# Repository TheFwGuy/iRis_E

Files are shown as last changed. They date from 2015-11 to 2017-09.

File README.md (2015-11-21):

iRis project with Energia

To compile, Set Energia to have the library included and open iRis.ino.
This directory should be placed in the main directory where the sketches are
kept.

It is necessary to have these libraries installed in the library directory:

- LCD_protocol_terminal
- LCD_screen
- LiquidCrystal
- SD
- Adafruit_Sensor_master
- Adafruit_TSL2561_master

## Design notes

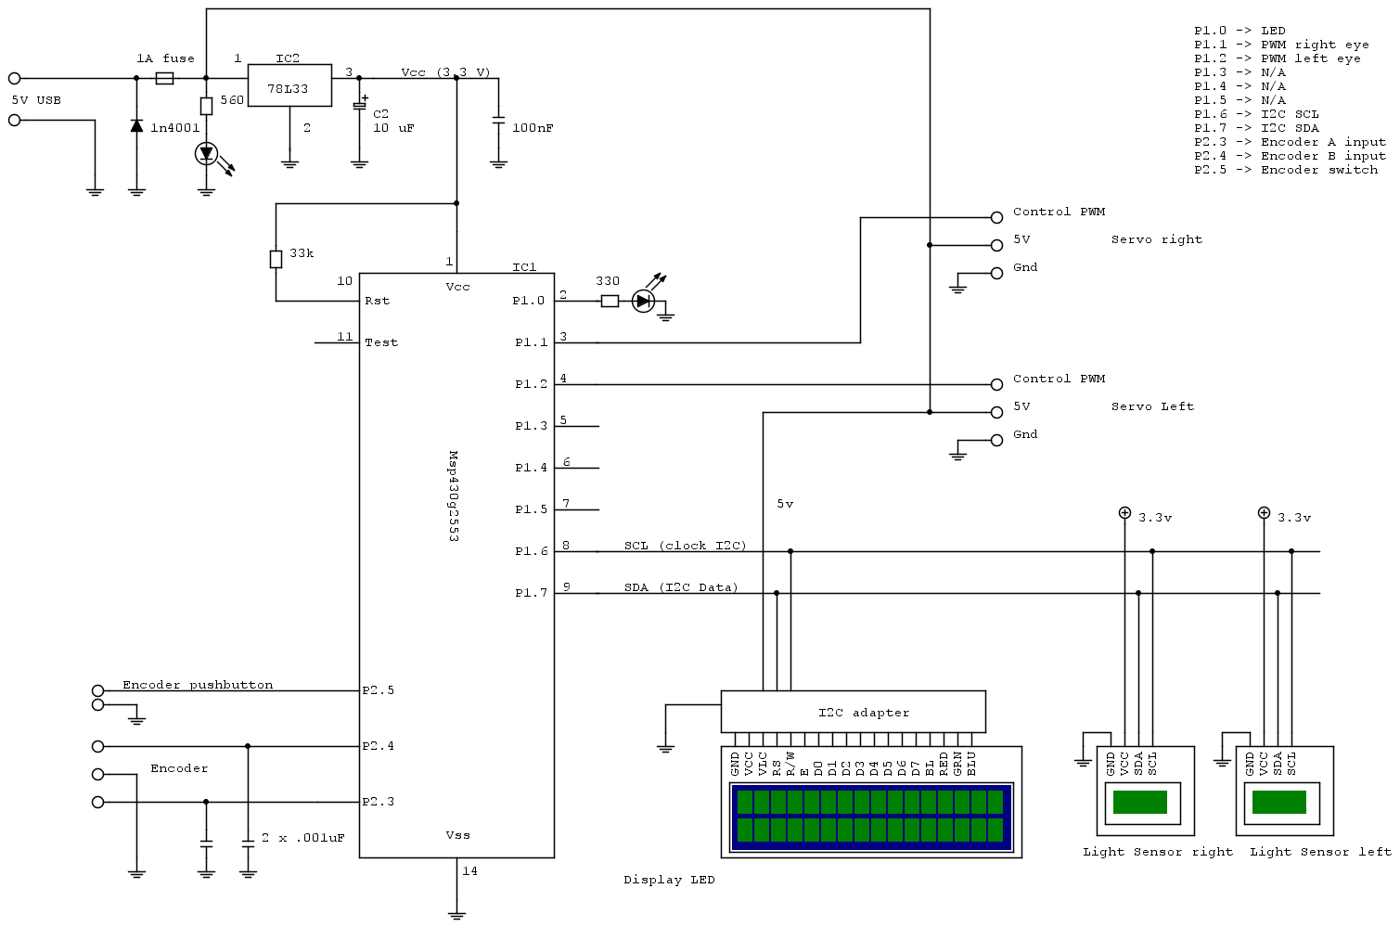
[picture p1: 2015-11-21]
Fidocad/iris_energia.png

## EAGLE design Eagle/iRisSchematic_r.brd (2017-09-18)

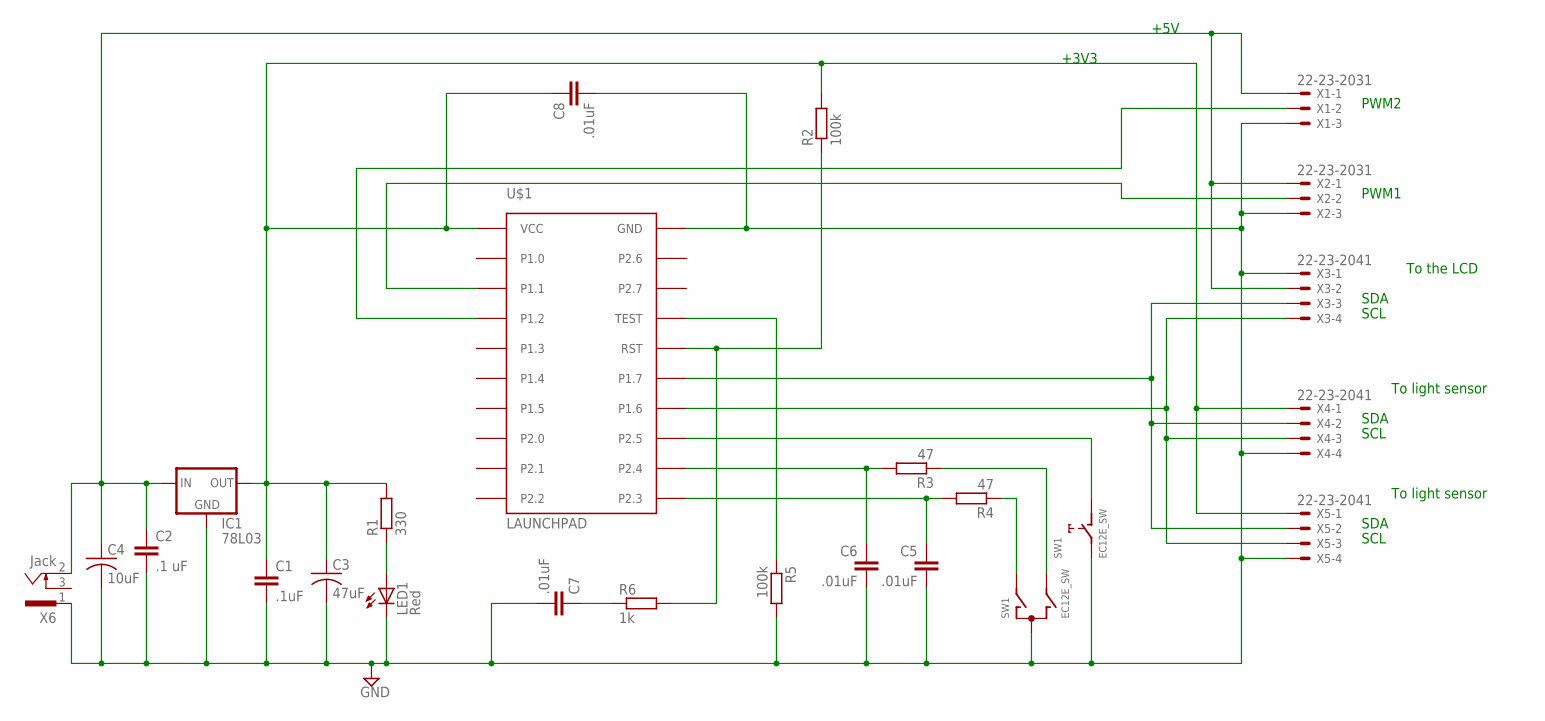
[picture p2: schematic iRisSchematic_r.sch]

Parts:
C1: .1uF; C2.5-2
C2: .1 uF; C2.5-2
C3: 47uF; C025-030X050
C4: 10uF; C025-030X050
C5, C6, C7, C8: .01uF; C2.5-2
IC1: 78L03; 78LXX
LED1: Red; LED_LD260
R1: 330; 0204/5
R2, R5: 100k; 0204/5
R3, R4: 47; 0204/5
R6: 1k; 0204/5
SW1: EC12E_SW; ALPS_EC12E_SW
U$1: LAUNCHPAD
X1, X2: 22-23-2031
X3, X4, X5: 22-23-2041
X6: Jack; SCD-014-A

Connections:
GND: C1.2, C2.2, C3.2, C4.2, C5.2, C6.2, C7.2, C8.2, IC1.GND, LED1.K (C), R5.2, SW1.C, SW1.E (2), U$1.GND, X1.3, X2.3, X3.1, X4.4, X5.4, X6.1
unnamed: LED1.A, R1.1
unnamed: SW1.D (1), U$1.P2.5
unnamed: C5.1, R4.2, U$1.P2.3
unnamed: C6.1, R3.2, U$1.P2.4
unnamed: U$1.P1.1, X2.2
unnamed: R5.1, U$1.TEST
unnamed: U$1.P1.6, X3.4, X4.3, X5.3
unnamed: R2.1, R6.2, U$1.RST
unnamed: C1.1, C3.1, C8.1, IC1.OUT, R1.2, R2.2, U$1.VCC, X4.1, X5.1
unnamed: R3.1, SW1.B
unnamed: R4.1, SW1.A
unnamed: C7.1, R6.1
unnamed: C2.1, C4.1, IC1.IN, X1.1, X2.1, X3.2, X6.2
unnamed: U$1.P1.2, X1.2
unnamed: U$1.P1.7, X3.3, X4.2, X5.2

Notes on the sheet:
PWM2
PWM1
SCL
SDA
+3V3
+5V
To light sensor
To the LCD

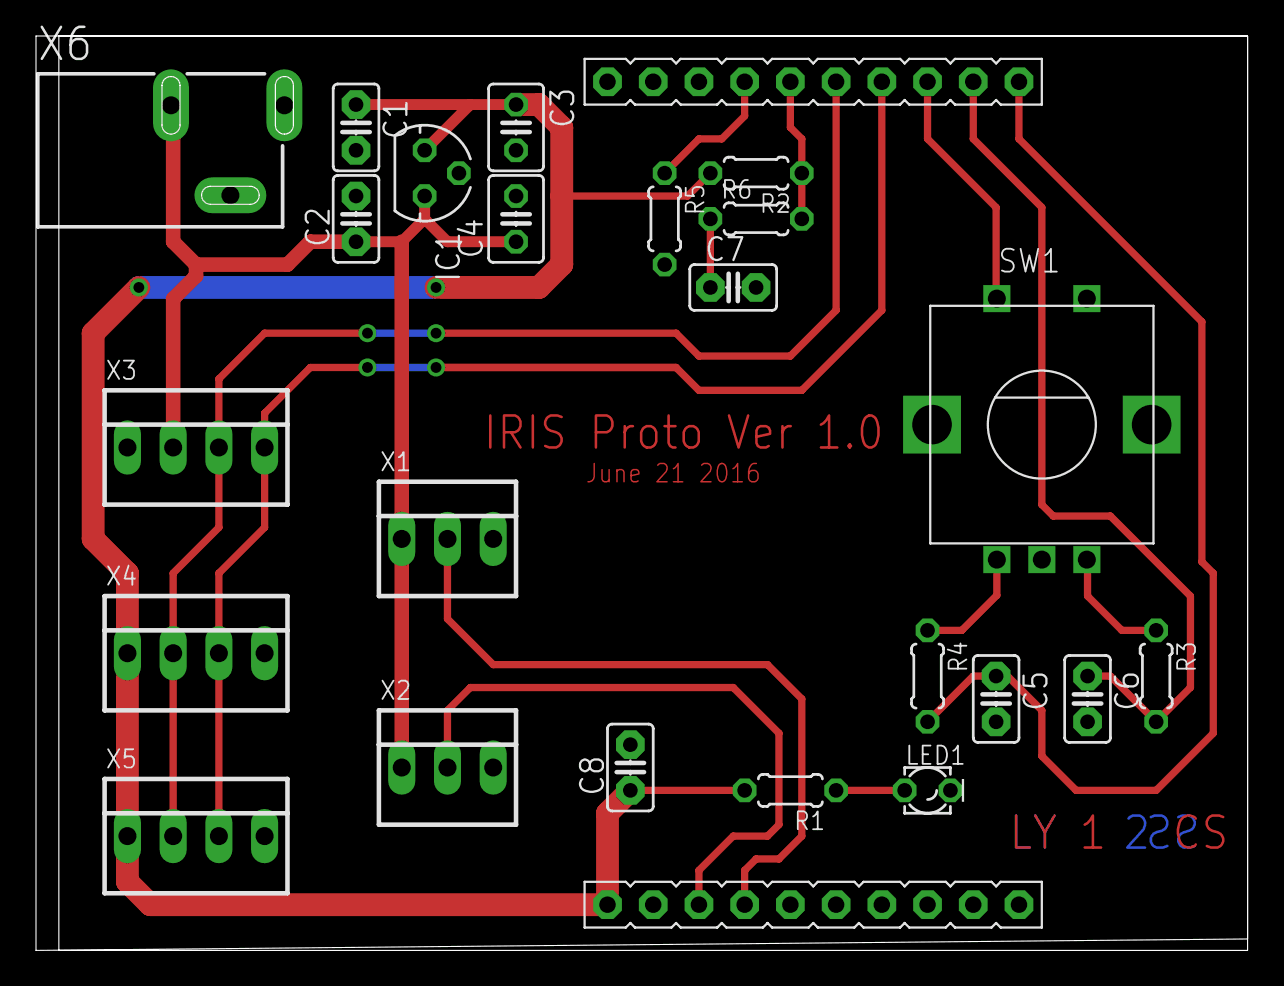
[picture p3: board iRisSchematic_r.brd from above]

Board: 2 copper layers, 67.3 x 50.8 mm, 24 parts (0 on the bottom side), 16 nets.

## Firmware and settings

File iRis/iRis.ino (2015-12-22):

/**
 *  iRis project with Energia
 *  @Auth TheFwGuy
 *  November 2015
 *  @Brief Artifical iris control with MSP430g2553
 *
 */

#include <Wire.h>
#include <LCD.h>
#include <LiquidCrystal_I2C.h>  // F Malpartida's NewLiquidCrystal library
#include <Servo.h> 
#include <Adafruit_Sensor.h>
#include <Adafruit_TSL2561_U.h>
 
/* Function prototypes */


/* Define I2C Address  */

#define I2C_ADDR 0x3F
#define BACKLIGHT_PIN  3

#define Rs_pin  0
#define Rw_pin  1
#define En_pin  2
#define D4_pin  4
#define D5_pin  5
#define D6_pin  6
#define D7_pin  7

#define  LED_OFF  0
#define  LED_ON  1

LiquidCrystal_I2C  lcd(I2C_ADDR,En_pin,Rw_pin,Rs_pin,D4_pin,D5_pin,D6_pin,D7_pin, BACKLIGHT_PIN, POSITIVE);

Servo rightEye;		/* create servo object to control a servo for the right eye */
Servo leftEye;		/* create servo object to control a servo for the left eye */

Adafruit_TSL2561_Unified tsl_R = Adafruit_TSL2561_Unified(TSL2561_ADDR_FLOAT, 12345);
Adafruit_TSL2561_Unified tsl_L = Adafruit_TSL2561_Unified(TSL2561_ADDR_LOW, 12345);

/*
 *  I/O defines
 */

#define LED_INFO   2            /* P1_0 */
#define EYE_RIGHT_PWM  3	/* P1_1 */
#define EYE_LEFT_PWM   4	/* P1_2 */

#define SELBTN     13		/* P2_5 */

#define ENC_A   P2_3
#define ENC_B   P2_4

#define KEYIsPressed(key) (!digitalRead(key))
#define KEYIsNotPressed(key) (digitalRead(key))

/*
 *  PWM related defines
 */

#define MAX_LIGHT_VALUE  3000
#define MAX_ENCODER_VALUE  250
#define MIN_PWM_VALUE  14
#define MAX_PWM_VALUE  180

/*
 *  I2C mode 
 *  SDA P1_7 Pin 14
 *  SCL P1_6 Pin 13 
 */

#define NORMAL  0
#define CALIBRATING 1
#define SETTING 2

/*
 *  Global variables
 */

char buffer[20];		/* Generic buffer for display purpose */
char main_status = NORMAL;
short Encoder_value = 0;
short Old_encoder_value = 0;
short Pwm_R_position = MIN_PWM_VALUE;
short Pwm_L_position = MIN_PWM_VALUE;


/* Interrupt service encoder function */

void doEncoder() 
{
   /* If pinA and pinB are both high or both low, it is spinning
    * forward. If they're different, it's going backward.
    *
    * For more information on speeding up this process, see
    * [Reference/PortManipulation], specifically the PIND register.
    */
   if (digitalRead(ENC_A) == digitalRead(ENC_B)) 
   {
      if(Encoder_value<MAX_ENCODER_VALUE)
         Encoder_value++;
   }
   else 
   {
      if(Encoder_value>0)
         Encoder_value--;
   }
}

void configureSensor(void)
{
  /* You can also manually set the gain or enable auto-gain support */
  // tsl.setGain(TSL2561_GAIN_1X);      /* No gain ... use in bright light to avoid sensor saturation */
  // tsl.setGain(TSL2561_GAIN_16X);     /* 16x gain ... use in low light to boost sensitivity */
  tsl_R.enableAutoRange(true);            /* Auto-gain ... switches automatically between 1x and 16x */
  tsl_L.enableAutoRange(true);            /* Auto-gain ... switches automatically between 1x and 16x */
  
  /* Changing the integration time gives you better sensor resolution (402ms = 16-bit data) */
  tsl_R.setIntegrationTime(TSL2561_INTEGRATIONTIME_13MS);      /* fast but low resolution */
  tsl_L.setIntegrationTime(TSL2561_INTEGRATIONTIME_13MS);      /* fast but low resolution */
  // tsl.setIntegrationTime(TSL2561_INTEGRATIONTIME_101MS);  /* medium resolution and speed   */
  // tsl.setIntegrationTime(TSL2561_INTEGRATIONTIME_402MS);  /* 16-bit data but slowest conversions */

}


void setup()
{
   rightEye.attach(EYE_RIGHT_PWM);	/* attaches the servo to the pin */
   leftEye.attach(EYE_LEFT_PWM);        /* attaches the servo to the pin */

   // put your setup code here, to run once:
   pinMode(LED_INFO,OUTPUT);
   digitalWrite(LED_INFO,LOW);		/* Turn LED OFF */
  
   pinMode(SELBTN,INPUT_PULLUP);
   pinMode(ENC_A,INPUT_PULLUP);
   pinMode(ENC_B,INPUT_PULLUP); 

   /* Setup the sensor gain and integration time */
   configureSensor();

   lcd.setBacklightPin(BACKLIGHT_PIN, POSITIVE); // POSITIVE); //NEGATIVE);
   lcd.setBacklight(LED_ON);
   lcd.backlight();
    
   lcd.begin(16,2);               // initialize the lcd 

//  lcd.createChar (0, smiley);    // load character to the LCD
//  lcd.createChar (1, armsUp);    // load character to the LCD
//  lcd.createChar (2, frownie);   // load character to the LCD

   lcd.clear();
   lcd.home ();                   // go home
   lcd.display();
   lcd.print("iRis Run        ");  
   lcd.setCursor ( 0, 1 );        // go to the next line
   lcd.print ("TheFwGuy    1.0");      

   rightEye.write(Pwm_R_position);
   leftEye.write(Pwm_L_position);
  
   delay(1000);
  
   attachInterrupt(ENC_A,doEncoder,CHANGE);
}


void loop()
{
   if(KEYIsPressed(SELBTN))
   {
      while(KEYIsPressed(SELBTN));
      switch(main_status)
      {
         case NORMAL:
            lcd.home ();                   // go home
            lcd.print("iRis Calibrating");  
            main_status = CALIBRATING;
            break;

         case CALIBRATING:
            lcd.home ();                   // go home
            lcd.print("iRis Setting     ");  
            main_status = SETTING;
            Encoder_value = 0;
            break;
      
         default:
         case SETTING:
            lcd.home ();                   // go home
            lcd.print("iRis Run        ");  
            main_status = NORMAL;
            break;
      }
   }    
      
   switch(main_status)
   {
      case NORMAL:
         /* Get a new sensor event */ 
         sensors_event_t event_R;
         sensors_event_t event_L;
   
         tsl_R.getEvent(&event_R);
         tsl_L.getEvent(&event_L);

         lcd.setCursor ( 0, 1 );         /* Print PWM values */
         lcd.print ("L:       R:    ");  /* Left at 3, right at 11 */
 
         /* Display the results (light is measured in lux) */
         if (event_R.light)
         {
            Pwm_R_position = map(event_R.light, 0, MAX_LIGHT_VALUE, MIN_PWM_VALUE, MAX_PWM_VALUE);
            
            lcd.setCursor ( 3, 1 );
            lcd.print(Pwm_R_position);
            
            rightEye.write(Pwm_R_position);
         }
   
         if (event_L.light)
         {
            Pwm_L_position = map(event_L.light, 0, MAX_LIGHT_VALUE, MIN_PWM_VALUE, MAX_PWM_VALUE);

            lcd.setCursor ( 11, 1 );
            lcd.print(Pwm_L_position);

            leftEye.write(Pwm_L_position);
         }
         delay(10);
         break;
         
      case CALIBRATING:   
         if(Encoder_value != Old_encoder_value)
         {
            Old_encoder_value = Encoder_value;
            Pwm_R_position = map(Encoder_value, 0, MAX_ENCODER_VALUE, MIN_PWM_VALUE, MAX_PWM_VALUE);
            Pwm_L_position = map(Encoder_value, 0, MAX_ENCODER_VALUE, MIN_PWM_VALUE, MAX_PWM_VALUE);
      
            lcd.setCursor ( 0, 1 );         /* Print PWM values */
            lcd.print ("L:       R:    ");  /* Left at 3, right at 11 */
            lcd.setCursor ( 3, 1 );
            lcd.print(Pwm_R_position);
            lcd.setCursor ( 11, 1 );
            lcd.print(Pwm_L_position);
   
            rightEye.write(Pwm_R_position);
            leftEye.write(Pwm_L_position);
            delay(10);
         }
         break;
         
      case SETTING:   
         if(Encoder_value != Old_encoder_value)
         {
            Old_encoder_value = Encoder_value;
            
            lcd.setCursor ( 0, 1 );         /* Print Menu */
            lcd.print ("Menu TBD       ");  

         }
         break;
         
   }
}

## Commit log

2015-11-21 Derived from UVBoxTimer - basic handling PWM and encoder
2015-12-22 Added second sensor reading - calibration - menu selection
2017-09-18 Added Eagle schematics prototype on Launchpad
    [DRILEGEND.CFG, iRisSchematic_r.brd, iRisSchematic_r.sch]
2017-09-18 Moved from generic schematic - old
